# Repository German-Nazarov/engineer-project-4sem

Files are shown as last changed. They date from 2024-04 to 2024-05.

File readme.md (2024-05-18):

# ФАКТ.Синтезатор
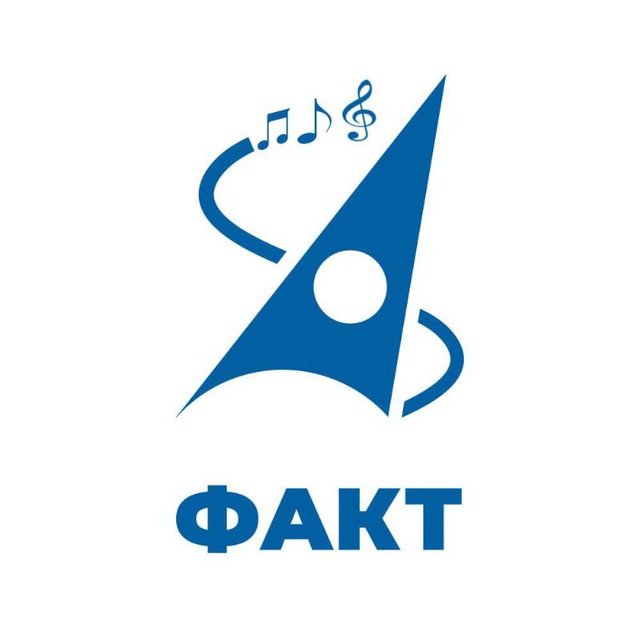
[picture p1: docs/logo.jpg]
Логотип


DIY синтезатор, разработанный и собранный командой студентов второго курса ФАКТ МФТИ.

## Струкрура репозитория
- __src/__ - исходный код, используется Arduino IDE
- __docs/__ - руководство пользователя к синтезатору, логотип команды, схема устройства, протокол испытаний
- __body/__ - файлы компонентов корпуса, используется CorelDraw 
- __archive/__ - исходный код проекта на начальном этапе разработки
## Полезные ссылки
- Приветственная [презентация](https://docs.google.com/presentation/d/1jiTuCDYLhv5Om5ewJSXBUfSQBudySQsCCXH7HL0cz3s/edit?usp=sharing) проекта
- Финальная [презентация](https://drive.google.com/file/d/13GRy12x8nt7UOJpUng1tQ2erg40VcWlq/view?usp=sharing) c __защиты__ проекта
- Telegram-канал [ФАКТ.Синтезатор](https://t.me/DIY_Synth)
- Raspberry Pi Pico [распиновка](https://www.raspberrypi.com/documentation/microcontrollers/images/pico-pinout.svg)
## Использованные инструменты
- Микроконтроллер RP2040 ([Raspberry Pi Pico](https://www.raspberrypi.com/products/raspberry-pi-pico/))
- Среда разработки (IDE) [Arduino IDE](https://www.arduino.cc/en/software)
- RP Pico [Arduino core](https://github.com/earlephilhower/arduino-pico)
- Библиотека для синтеза звука [Mozzi](https://sensorium.github.io/Mozzi/)
## Подробнее о продукте
Разработан в рамках _курса общеинженерной подготовки_ при поддержке [Физтех.Фабрики](https://miptfab.ru/).    
Основные функции:
- Выбор из пяти октав
- Клавиатура из 13 кнопок (октава + 1)
- Три вида сигнала - синусоида, пила, прямоугольник

Ключевые особенности:
- Подключение к микшеру/колонке через разъём jack 6.35мм
- Питание от батареек AA (2 шт.)
- Индикация работы
- Корпус из дерева

## Этапы разработки, возникшие трудности
1. Сбор команды, распределение задач
2. Выбор микроконтроллера, написание hello world со светодиодом на C
3. Создание telegram-канала, репозитория и презентации продукта
4. Прохождение курса работы с электроникой на Физтех.Фабрике, покупка аудио разъема
5. Изучение готовых продуктов, их сравнению (спасибо Евгению с Физтех.Фабрики!)
6. Создание прототипа клавиатуры из 12 тактовых кнопок
7. Получение первой звучащей ноты (440Гц синусоида) с помощью ЦАПа на ШИМе (библиотека Mozzi)
8. Покупка готового детского синтезатора, изучение его устройства и схемы питания, попытка использовать его клавиатуру
9. Фильтрация шумов, применили RC-фильтр с частотой 6 kHz (R = 270Ω, C = 100nF)
10. Реализация смены пяти октав
11. Прохождение курса по раскрою на станках с ЧПУ и лазерной гравировке
12. Реализация смены формы сигнала (синус, пила, меандр)
13. Начало переноса синтезатора с беспаечной макетной платы на плату для пайки
14. Создание прототипа корпуса
15. _Возгорание батарейного отсека_
16. Начало разработки финальной презентации и подготовки к защите
17. Завершение пайки устройства, производство финальной версии корпуса
18. Сборка синтезатора в готовое изделие, проверка работоспособности
19. Запись демонстрационных видео, использование продукта для создания музыкального трека
20. Работа над презентацией, обсуждение идей, подготовка слайдов, распределение ролей
21. Тестирование независимыми лицами, сбор обратной связи
22. Написание инструкции, проведение испытаний и составление их протокола
23. Подготовка речи, репетиция
24. Защита проекта на [прямой трансляции](https://vk.com/video-198342309_456239040) (таймкод 22:00, выступили вторыми)
25. Победа!

__Больше информации__ (дневник разработки, примеры звучания, анонсы) можно найти в нашем [telegram-канале](https://t.me/DIY_Synth).

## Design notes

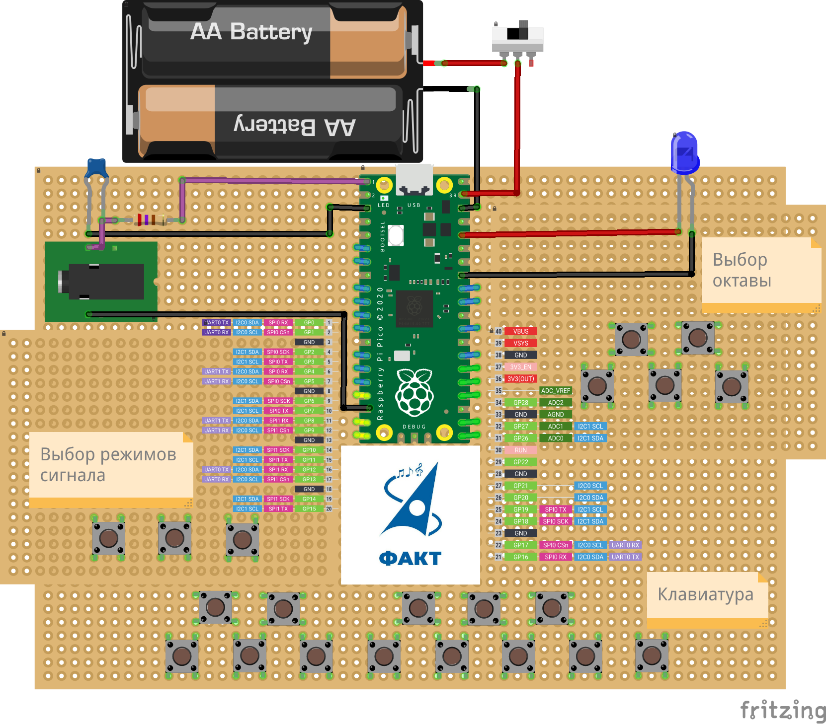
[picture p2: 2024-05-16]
docs/schematic_bb.png

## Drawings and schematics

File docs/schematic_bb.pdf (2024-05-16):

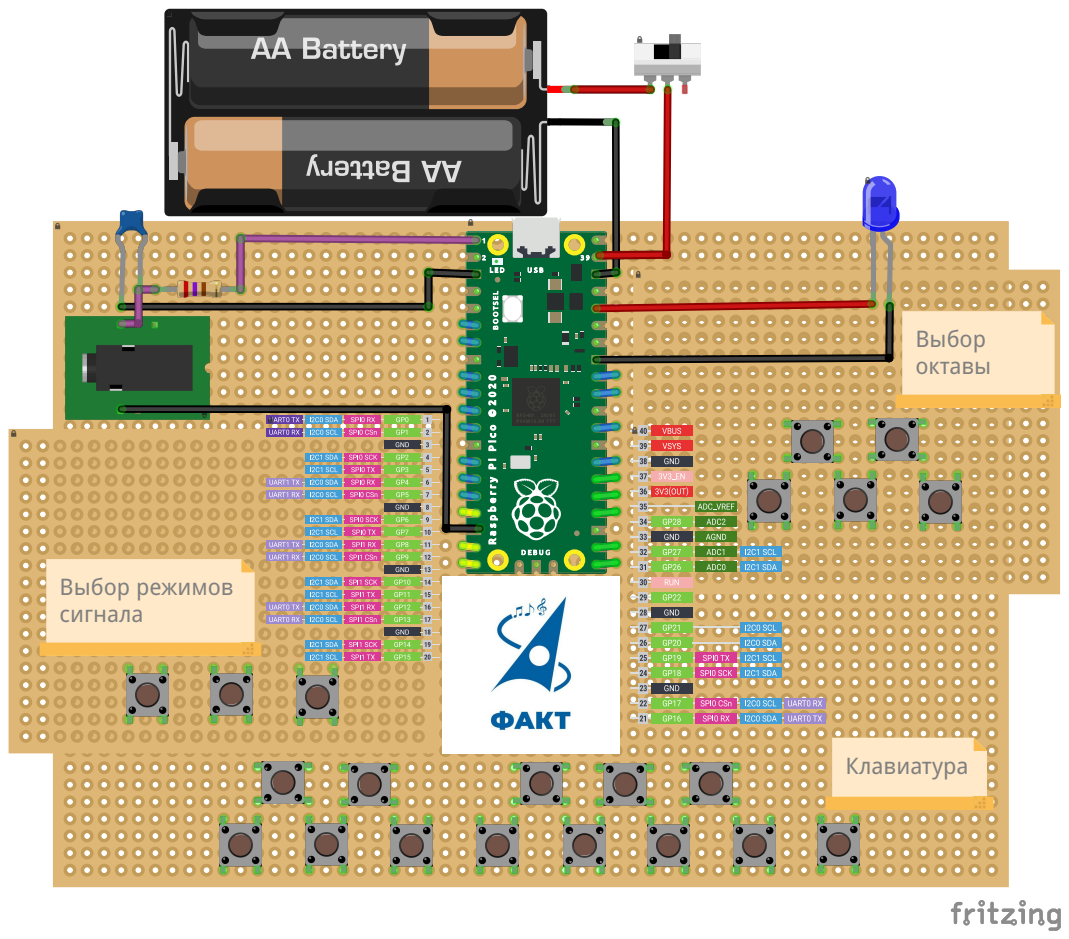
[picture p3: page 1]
Клавиатура; Выбор октавы; Выбор режимов сигнала

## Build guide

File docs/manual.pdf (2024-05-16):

# Инструкция по использованию синтезатора

## 1 Краткое описание

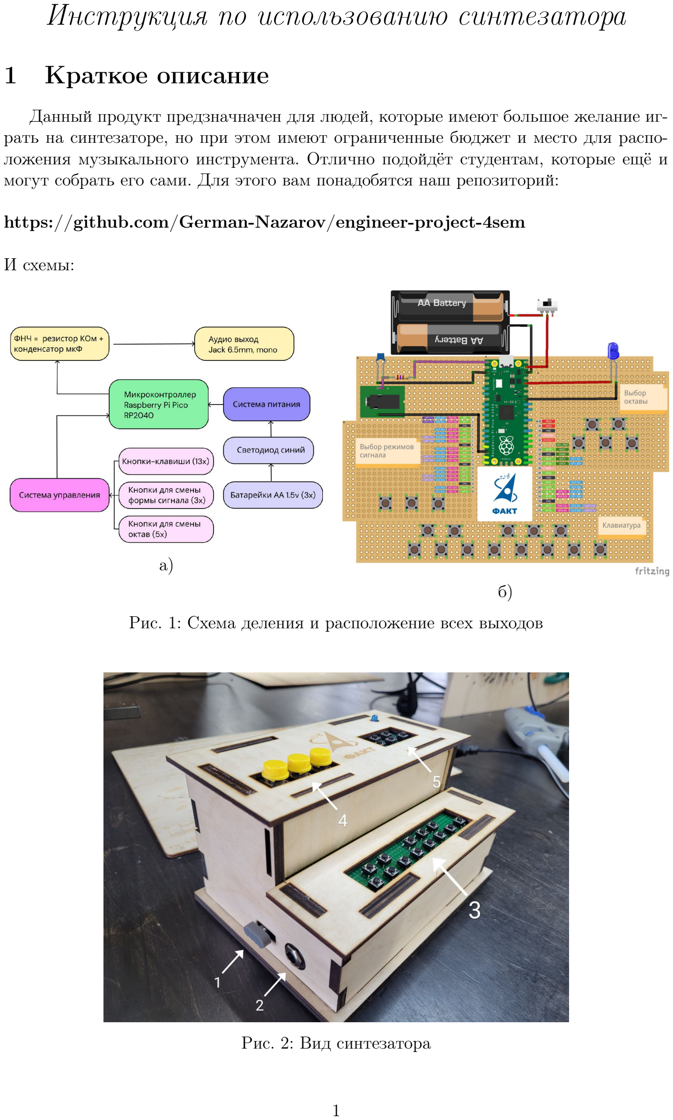
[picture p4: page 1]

Данный продукт предзначначен для людей, которые имеют большое желание играть на синтезаторе, но при этом имеют ограниченные бюджет и место для расположения музыкального инструмента. Отлично подойдёт студентам, которые ещё и могут собрать его сами. Для этого вам понадобятся наш репозиторий:

https://github.com/German-Nazarov/engineer-project-4sem

И схемы:

а)

б)

Рис. 1: Схема деления и расположение всех выходов

Рис. 2: Вид синтезатора

## 2 Игра на синтезаторе

Для использования музыкального инструмента вам необходимо:
1) Включить его, для этого надо перевести переключатель 1 в левое положение.
2) Подключить соответсвующий интсрумент для прослушивания сигнала (усилитель, колонка) через аудиовыход 2.
3) Играть с помощью кнопок на панели 3. Они здесь расположены по подобию клавиш на фортепиано (верхний ряд - чёрные кнопки, нижний ряд - белые кнопки)
4) Для переключения формы сигнала следует воспользоваться панелью 4.
Расположение кнопки | Форма сигнала
Левая | Прямоугольный
Центральная | Пилообразный
Правая | Синусоидальный

Таблица 1: Смена формы сигнала

5) Для смены октавы нужно нажать соответсвующую кнопку на панели 5.
Расположение кнопки | Октава
1, самая левая | Большая
2 | Малая
3 | Первая
4 | Вторая
5, самая правая | Третья

Таблица 2: Смена октавы

6) По завершении игры следует перевести кнопку 1 в правое положение и отключить устройство прослушивания.

## 3 Компоненты

Наименование | Количество, шт
Макетная плата для пайки 100 × 150 мм, одностороняя | 1
Макетная плата для пайки 50 × 70 мм, двухсторонняя | 2
RP2040 (Raspberry Pi Pico) | 1
Кнопка тактовая малая | 18
Кнопка тактовая большая | 3
Аудио выход Jack 6.5 мм, mono | 1
Резистор 270 Ом | 1
Конденсатор 100 нФ | 1
Провода 24 AWG, 10 см | 30
Батарейный отсек 2 × АА закрытый | 1
Батарейка АА | 2
Светодиод синий | 1
Переключатель | 1

## 4 Меры безопсности

Данный продукт следует держать вдали от воды и других жидкостей, прямого и длительного контакта с солнечным излучением, очагов возгорания и детей.

Также для более длительного сохранения корпуса, нельзя держать синтезатор вблизи батарей и других подобных объектов, вблизи которых реализуется резкий перепад температур.

## 5 Контакты

По всем вопросам обращайтесь в телеграме: https://t.me/DIY_Synth

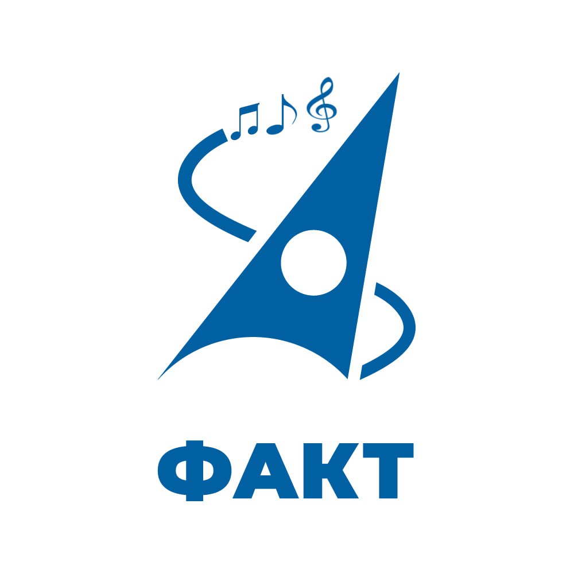
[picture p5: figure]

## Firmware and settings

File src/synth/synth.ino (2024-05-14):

#include <MozziGuts.h>
#include <Oscil.h> // oscillator template
#include <tables/sin8192_int8.h> // sine table for oscillator
#include <tables/saw8192_int8.h>
#include <tables/smoothsquare8192_int8.h>
#include "synth.h"

// #define DEBUG

// use: Oscil <table_size, update_rate> oscilName (wavetable), look in .h file of table #included above
// default here is SIN2048_NUM_CELLS and SIN2048_DATA
Oscil <SIN8192_NUM_CELLS, AUDIO_RATE> aSIN(SIN8192_DATA);
Oscil <SAW8192_NUM_CELLS, AUDIO_RATE> aSAW(SAW8192_DATA);
Oscil <SMOOTHSQUARE8192_NUM_CELLS, AUDIO_RATE> aSQR(SMOOTHSQUARE8192_DATA);
// CONTROL_RATE specifies how frequently update_control() is executed
#define CONTROL_RATE 64           // Hz, powers of 2 are most reliable
enum mode { NONE, SIN, SAW, SQR };
int k = mode::SIN;               // индекс, по которому определяем какой сигнал на выходе

float Octaves[5][13] = {0};
void setup(){
  startMozzi(CONTROL_RATE); // :)
  // startMozzi() sets up an interrupt for audio output at a sample rate of 16384 Hz.
  /*This sets up one timer to call updateControl() at the rate chosen and
  another timer which works behind the scenes to send audio samples to the output pin at the fixed rate of
  16384 Hz.*/

  aSIN.setFreq(440);  // set the frequency
  aSAW.setFreq(440);
  aSQR.setFreq(440);

  #ifdef DEBUG
  Serial.begin(9600); // begin Serial com for debugging purposes
  #endif

  setup_button_pins();
  setup_octave_table();
}

int index_Octave = 0;
int freq_to_set = 0;
void updateControl() {
// put changing controls in here
  freq_to_set = 0;  // reset the frequency so it's played only as long as a button is pressed

  // changing octave
  if (!digitalRead(OCT_BIG)) {
    index_Octave = 0;
    #ifdef DEBUG
    Serial.println("Big Octave");
    #endif
  }
  if (!digitalRead(OCT_SMALL)) {
    index_Octave = 1;
    #ifdef DEBUG
    Serial.println("Small Octave");
    #endif
  }
  if (!digitalRead(OCT_1)) {
    index_Octave = 2;
    #ifdef DEBUG
    Serial.println("1 Octave");
    #endif
  }
  if (!digitalRead(OCT_2)) {
    index_Octave = 3;
    #ifdef DEBUG
    Serial.println("2 Octave");
    #endif
  }
  if (!digitalRead(OCT_3)) {
    index_Octave = 4;
    #ifdef DEBUG
    Serial.println("3 Octave");
    #endif
  }

  // changing keys
  if (!digitalRead(BTN_1)) {
    freq_to_set = Octaves[index_Octave][0];
    #ifdef DEBUG
    Serial.println("on btn1");
    #endif
  }
  if (!digitalRead(BTN_2)) {
    freq_to_set = Octaves[index_Octave][1];
    #ifdef DEBUG
    Serial.println("on btn2");
    #endif
  }
  if (!digitalRead(BTN_3)) {
    freq_to_set = Octaves[index_Octave][2];
    #ifdef DEBUG
    Serial.println("on btn3");
    #endif
  }
  if (!digitalRead(BTN_4)) {
    freq_to_set = Octaves[index_Octave][3];
    #ifdef DEBUG
    Serial.println("on btn4");
    #endif
  }
  if (!digitalRead(BTN_5)) {
    freq_to_set = Octaves[index_Octave][4];
    #ifdef DEBUG
    Serial.println("on btn5");
    #endif
  }
  if (!digitalRead(BTN_6)) {
    freq_to_set = Octaves[index_Octave][5];
    #ifdef DEBUG
    Serial.println("on btn6");
    #endif
  }
  if (!digitalRead(BTN_7)) {
    freq_to_set = Octaves[index_Octave][6];
    #ifdef DEBUG
    Serial.println("on btn7");
    #endif
  }
  if (!digitalRead(BTN_8)) {
    freq_to_set = Octaves[index_Octave][7];
    #ifdef DEBUG
    Serial.println("on btn8");
    #endif
  }
  if (!digitalRead(BTN_9)) {
    freq_to_set = Octaves[index_Octave][8];
    #ifdef DEBUG
    Serial.println("on btn9");
    #endif
  }
  if (!digitalRead(BTN_10)) {
    freq_to_set = Octaves[index_Octave][9];
    #ifdef DEBUG
    Serial.println("on btn10");
    #endif
  }
  if (!digitalRead(BTN_11)) {
    freq_to_set = Octaves[index_Octave][10];
    #ifdef DEBUG
    Serial.println("on btn11");
    #endif
  }
  if (!digitalRead(BTN_12)) {
    freq_to_set = Octaves[index_Octave][11];
    #ifdef DEBUG
    Serial.println("on btn12");
    #endif
  }
  if (!digitalRead(BTN_13)) {
    freq_to_set = Octaves[index_Octave][12];
    #ifdef DEBUG
    Serial.println("on btn13");
    #endif
  }

  // changing type of output signal
  if (!digitalRead(SIN_BTN)) {
    k = mode::SIN;
    #ifdef DEBUG
    Serial.println("SIN");
    #endif
  }
  if (!digitalRead(SAW_BTN)) {
    k = mode::SAW;
    #ifdef DEBUG
    Serial.println("SAW");
    #endif
  }
  if (!digitalRead(SQR_BTN)) {
    k = mode::SQR;
    #ifdef DEBUG
    Serial.println("SQR");
    #endif
  }

  aSIN.setFreq(freq_to_set);
  aSAW.setFreq(freq_to_set);
  aSQR.setFreq(freq_to_set);
}

AudioOutput_t updateAudio(){
  // return an int signal centred around 0
  switch(k) {
    case mode::SIN:
      return MonoOutput::from8Bit(aSIN.next());
      break;
    case mode::SAW:
      return MonoOutput::from8Bit(aSAW.next());
      break;
    case mode::SQR:  
      return MonoOutput::from8Bit(aSQR.next());
      break;
    case mode::NONE:
    default:
      return 0;
      break;
  }
  // Oscil’s next() method returns a signed 8 bit value from the oscillator’s wavetable.
  // The int return value of updateAudio() must be in the range -244 to 243 in Mozzi’s default STANDARD audio mode.
}


void loop(){
  audioHook(); // required here
}

/* ---- КОД НАСТРОЙКИ ---- */
void setup_octave_table() {
  for(size_t i = 0; i < 13; i++) {
    Octaves[0][i] = Octave_big[i];
    Octaves[1][i] = Octave_small[i];
    Octaves[2][i] = Octave_1[i];
    Octaves[3][i] = Octave_2[i];
    Octaves[4][i] = Octave_3[i];
  }
}

void setup_button_pins() {
  // Смотрим какая октава выбрана
  pinMode(OCT_1, INPUT_PULLUP);
  pinMode(OCT_2, INPUT_PULLUP);
  pinMode(OCT_3, INPUT_PULLUP);
  pinMode(OCT_BIG, INPUT_PULLUP);
  pinMode(OCT_SMALL, INPUT_PULLUP);

  // Смотрим какие клавиши нажаты
  pinMode(BTN_1, INPUT_PULLUP);
  pinMode(BTN_2, INPUT_PULLUP);
  pinMode(BTN_3, INPUT_PULLUP);
  pinMode(BTN_4, INPUT_PULLUP);
  pinMode(BTN_5, INPUT_PULLUP);
  pinMode(BTN_6, INPUT_PULLUP);
  pinMode(BTN_7, INPUT_PULLUP);
  pinMode(BTN_8, INPUT_PULLUP);
  pinMode(BTN_9, INPUT_PULLUP);
  pinMode(BTN_10, INPUT_PULLUP);
  pinMode(BTN_11, INPUT_PULLUP);
  pinMode(BTN_12, INPUT_PULLUP);
  pinMode(BTN_13, INPUT_PULLUP);

  // Смотрим какой тип сигнала на выходе
  pinMode(SIN_BTN, INPUT_PULLUP);
  pinMode(SAW_BTN, INPUT_PULLUP);
  pinMode(SQR_BTN, INPUT_PULLUP);
}

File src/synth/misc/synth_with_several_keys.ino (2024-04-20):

#include <MozziGuts.h>
#include <Oscil.h> // oscillator template
#include <tables/sin2048_int8.h> // sine table for oscillator

// use: Oscil <table_size, update_rate> oscilName (wavetable), look in .h file of table #included above
Oscil <SIN2048_NUM_CELLS, AUDIO_RATE> aSin1(SIN2048_DATA);
Oscil <SIN2048_NUM_CELLS, AUDIO_RATE> aSin2(SIN2048_DATA);
Oscil <SIN2048_NUM_CELLS, AUDIO_RATE> aSin3(SIN2048_DATA);
Oscil <SIN2048_NUM_CELLS, AUDIO_RATE> aSin4(SIN2048_DATA);
Oscil <SIN2048_NUM_CELLS, AUDIO_RATE> aSin5(SIN2048_DATA);
Oscil <SIN2048_NUM_CELLS, AUDIO_RATE> aSin6(SIN2048_DATA);
Oscil <SIN2048_NUM_CELLS, AUDIO_RATE> aSin7(SIN2048_DATA);
Oscil <SIN2048_NUM_CELLS, AUDIO_RATE> aSin8(SIN2048_DATA);
Oscil <SIN2048_NUM_CELLS, AUDIO_RATE> aSin9(SIN2048_DATA);
Oscil <SIN2048_NUM_CELLS, AUDIO_RATE> aSin10(SIN2048_DATA);
Oscil <SIN2048_NUM_CELLS, AUDIO_RATE> aSin11(SIN2048_DATA);
Oscil <SIN2048_NUM_CELLS, AUDIO_RATE> aSin12(SIN2048_DATA);


// use #define for CONTROL_RATE, not a constant
#define CONTROL_RATE 64 // Hz, powers of 2 are most reliable
// не занимать пин GP0
#define OCT_BIG 12
#define OCT_SMALL 11
#define OCT_1 10
#define OCT_2 9
#define OCT_3 8

#define BTN_1 16
#define BTN_2 17
#define BTN_3 18
#define BTN_4 19
#define BTN_5 20
#define BTN_6 21
#define BTN_7 22
#define BTN_8 26
#define BTN_9 27
#define BTN_10 28
#define BTN_11 14
#define BTN_12 13

float Octave_big[12] = {65.4064,	69.2957,	73.4162,	77.7817,	82.4069,	87.3071,	92.4986,	97.9989,	103.8262,	110,	116.5409,	123.4708};
float Octave_small[12] = {130.8128,	138.5913,	146.8324,	155.5635,	164.8138,	174.6141,	184.9972,	195.9977,	207.6523,	220,	233.0819,	246.9417};
float Octave_1[12] = {261.6256,	277.1826,	293.6648,	311.127,	329.6276,	349.2282,	369.9944,	391.9954,	415.3047,	440,	466.1638,	493.8833};
float Octave_2[12] = {523.2511,	554.3653,	587.3295,	622.254,	659.2551,	698.4565,	739.9888,	783.9909,	830.6094,	880,	932.3275,	987.7666};
float Octave_3[12] = {1046.5023,	1108.7305,	1174.6591,	1244.5079,	1318.5102,	1396.9129,	1479.9777,	1567.9817,	1661.2188,	1760,	1864.655,	1975.5332};

float Octaves[5][12] = {0};
for(size_t i =0; i < 12; i++){
Octaves[0][i] = Octave_big[i];
Octaves[1][i] = Octave_small[i];
Octaves[2][i] = Octave_1[i];
Octaves[3][i] = Octave_2[i];
Octaves[4][i] = Octave_3[i];
}

void setup(){
    startMozzi(CONTROL_RATE); // :)
    /*This sets up one timer to call updateControl() at the rate chosen and
    another timer which works behind the scenes to send audio samples to the output pin at the fixed rate of
    16384 Hz.
    */
    aSin.setFreq(440); // set the frequency

    Serial.begin(9600);
    // Смотрим какая октава выбрана
    pinMode(OCT_BIG, INPUT_PULLUP);
    pinMode(OCT_SMALL, INPUT_PULLUP);
    pinMode(OCT_1, INPUT_PULLUP);
    pinMode(OCT_2, INPUT_PULLUP);
    pinMode(OCT_3, INPUT_PULLUP);

    // Смотрим какие клавиши нажаты
    pinMode(BTN_1, INPUT_PULLUP);
    pinMode(BTN_2, INPUT_PULLUP);
    pinMode(BTN_3, INPUT_PULLUP);
    pinMode(BTN_4, INPUT_PULLUP);
    pinMode(BTN_5, INPUT_PULLUP);
    pinMode(BTN_6, INPUT_PULLUP);
    pinMode(BTN_7, INPUT_PULLUP);
    pinMode(BTN_8, INPUT_PULLUP);
    pinMode(BTN_9, INPUT_PULLUP);
    pinMode(BTN_10, INPUT_PULLUP);
    pinMode(BTN_11, INPUT_PULLUP);
    pinMode(BTN_12, INPUT_PULLUP);
}


int freq_to_set[12] = {0};
int index_Octave = 0;
int number_of_active_keys = 0;
void updateControl(){
    freq_to_set[12] = {0};
    index_Octave = 0;

    // put changing controls in here
    // changing octave
    if (!digitalRead(OCT_BIG)) {
        index_Octave = 0;
        Serial.println("Big Octave");
    }
    if (!digitalRead(OCT_SMALL)) {
        index_Octave = 1;
        Serial.println("Small Octave");
    }
    if (!digitalRead(OCT_1)) {
        index_Octave = 2;
        Serial.println("1 Octave");
    }
    if (!digitalRead(OCT_2)) {
        index_Octave = 3;
        Serial.println("2 Octave");
    }
    if (!digitalRead(OCT_3)) {
        index_Octave = 4;
        Serial.println("3 Octave");
    }

    // changing keys
    if (!digitalRead(BTN_1)) {
        freq_to_set[0] = Octaves[index_Octave][0];
        Serial.println("on btn1");
    }
    if (!digitalRead(BTN_2)) {
        freq_to_set[1] = Octaves[index_Octave][1];
        Serial.println("on btn2");
    }
    if (!digitalRead(BTN_3)) {
        freq_to_set[2] = Octaves[index_Octave][2];
        Serial.println("on btn3");
    }
    if (!digitalRead(BTN_4)) {
        freq_to_set[3] = Octaves[index_Octave][3];
        Serial.println("on btn4");
    }
    if (!digitalRead(BTN_5)) {
        freq_to_set[4] = Octaves[index_Octave][4];
        Serial.println("on btn5");
    }
    if (!digitalRead(BTN_6)) {
        freq_to_set[5] = Octaves[index_Octave][5];
        Serial.println("on btn6");
    }
    if (!digitalRead(BTN_7)) {
        freq_to_set[6] = Octaves[index_Octave][6];
        Serial.println("on btn7");
    }
    if (!digitalRead(BTN_8)) {
        freq_to_set[7] = Octaves[index_Octave][7];
        Serial.println("on btn8");
    }
    if (!digitalRead(BTN_9)) {
        freq_to_set[8] = Octaves[index_Octave][8];
        Serial.println("on btn9");
    }
    if (!digitalRead(BTN_10)) {
        freq_to_set[9] = Octaves[index_Octave][9];
        Serial.println("on btn10");
    }
    if (!digitalRead(BTN_11)) {
        freq_to_set[10] = Octaves[index_Octave][10];
        Serial.println("on btn11");
    }
    if (!digitalRead(BTN_12)) {
        freq_to_set[11] = Octaves[index_Octave][11];
        Serial.println("on btn12");
    }

    number_of_active_keys = 0;
    for(size_t i = 0; i < 12; i++) {
        if(freq_to_set[i] != 0){
            number_of_active_keys ++;
        }
    }



    aSin1.setFreq(freq_to_set[0]);
    aSin2.setFreq(freq_to_set[1]);
    aSin3.setFreq(freq_to_set[2]);
    aSin4.setFreq(freq_to_set[3]);
    aSin5.setFreq(freq_to_set[4]);
    aSin6.setFreq(freq_to_set[5]);
    aSin7.setFreq(freq_to_set[6]);
    aSin8.setFreq(freq_to_set[7]);
    aSin9.setFreq(freq_to_set[8]);
    aSin10.setFreq(freq_to_set[9]);
    aSin11.setFreq(freq_to_set[10]);
    aSin12.setFreq(freq_to_set[11]);

        
}


AudioOutput_t updateAudio(){
    int All_signal;
    if (number_of_active_keys != 0) {
        All_signal = (aSin1.next() + aSin2.next() + aSin3.next() + aSin4.next() + aSin5.next() + aSin6.next() +
                      aSin7.next() + aSin8.next() + aSin9.next() + aSin10.next() + aSin11.next() + aSin12.next()) /
                     number_of_active_keys;
    }
    else{All_signal = 0;}
    return MonoOutput::from8Bit(All_signal); // return an int signal centred around 0
}


void loop(){
    audioHook(); // required here
}

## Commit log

2024-04-04 Добавлен файл readme.md
2024-04-05 Чертёж кода
    Теперь будет 1 ветка
2024-04-19 Octaves))
    В первом коде просто добавление выбора октавы
    Во втором коде попытка вывода сразу нескольких сигналов + затухание звука
    Пока это сделано посредством уменьшения амплитуды (что не очень хорошо т.к. синус превращается в ступеньку), но возможно после получится изменять не амплитуду, а именно звук (но вряд ли т.к. вывод у 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
2024-04-20 Create synth_with_several_keys.ino
    several_keys - вроде должно просто ухудшаться качество звука, если нажимать несколько клавиш сразу.
    При этом звук от клавиши пропадает сразу как отпустить её
2024-05-04 fix: rewite code for better readability
    [Pico-breadboard.fzz, schematic.fzz]
2024-05-16 add: shematic, manual
    [Pico-breadboard.fzz, schematic.fzz]
2024-05-17 Add files from phystech-factory
    The files are designed for laser cutting and etching
2024-05-17 Added trials protocols
    [ФАКТ.Синтезатор_Протокол_испытаний.xlsx]
